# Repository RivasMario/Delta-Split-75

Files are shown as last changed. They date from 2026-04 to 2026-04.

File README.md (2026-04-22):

# Delta Split 75

Fork/mirror of the DeltaSplit75 V2 open-source keyboard: case DXF/DWG files, PCB gerbers, and 3D model. Reorganized for local iteration and fab prep.

## What this is

DeltaSplit 75 is a **dual-mode 75% keyboard**:

1. **One-piece mode** — left + right plates butt-join into a single unibody case; all keys present.
2. **Spread-split mode** — same PCB/plates but mounted in two separate shells with a physical gap between halves. At the seam there's a **detachable switch** that gets populated for one-piece mode and removed (or a blocker inserted) for spread mode.

The PCB is one ~322 × 120 mm board regardless of mode. Plates ship as **left + right DXFs** because the combined ~680 mm width exceeds most laser beds, and because the spread mode needs them as separate parts anyway.

## Layout

```
case/
  bezel/        top bezel — Standard / Winkeyless / blocked-corner
  left/
    plate/      MX, ALPS, ALPS+MX, MX Costars
    middle/     5× stacked in one DXF
    bottom/
  right/
    plate/      MX, ALPS, ALPS+MX   (no Costars variant)
    middle/
    bottom/
pcb/
  gerbers/      KiCad 4.0.6 output, 11 files (Cu/Mask/Paste/SilkS/Edge.Cuts/drills)
docs/
  DeltaSplit-Final.step    3D assembly
  deltasplit.pdf           original build doc
  PCB_Dimension.dwg
  ORIGINAL_README.md
archive/
  *.zip, *.bak             source archives, AutoCAD backups
```

## Stackup (top → bottom)

Designed for **3D printing** or acrylic stack. Total height ≈ **25.5 mm**.

| Qty | Component | Notes |
|----|---|---|
| 1  | Top Bezel | 3D print (one piece) |
| 2  | Switch Plates | Left + Right, 1.5mm Alu or 3D print |
| 2  | Mid Shells | Left + Right halves |
| 2  | Bottom Bases | Left + Right halves |

## Interconnect
*   **Original:** TRRS (unsafe hot-plugging).
*   **Modern (RP2040 Build):** USB-C to USB-C link.

## 3D print quantities (STLs in `output/3d/`)

Generated by `scripts/case_to_stl.py` — one STL per file, print the count listed.

| STL | Prints | Notes |
|-----|:---:|---|
| `bezel_standard.stl` / `bezel_winkeyless.stl` / `bezel_blocked.stl` | **1** | pick one variant |
| `plate_left_<variant>.stl` | **1** | pick one variant |
| `plate_right_<variant>.stl` | **1** | pick matching variant |
| `middle_left.stl` | **5** | STL contains one copy; source DXF had 5 stacked on sheet |
| `middle_right.stl` | **5** | same |
| `bottom_left.stl` | **1** |  |
| `bottom_right.stl` | **1** |  |

Total: 1 bezel + 2 plates + 10 middles + 2 bottoms = **15 parts** per keyboard.

## Next

See `PLATES.md` for plate variant matrix, `BUILD.md` for fab-order guide, `STATUS.md` for current issues / TODOs.

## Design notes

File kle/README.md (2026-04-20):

# KLE — DeltaSplit 75

`deltasplit75_raw.json` — user's on-record KLE for the DeltaSplit 75. Raw keyboard-layout-editor rows.

## Layout notes

- **Gap `{"x":2}`** in every row = the visual/physical split between LEFT and RIGHT halves.
- **Color coding:**
  - `#cccccc` — alphas
  - `#999999` — mods / function keys
  - `#6897ca` — arrow cluster
- **"Temp" keys** at end of rows 2–5 = placeholder labels on the right-hand column; rename when finalizing.
- **Row 6 (bottom)** has a 2u "Backspace" where a 2.75u Spacebar normally sits on the LEFT half — unusual. Check if this is the detachable seam switch or an intentional remap.
- **Seam switch / detachable key** — not yet identified in this KLE. If the spread-split variant omits a key, mark it with `{d:true}` (decal) or produce `deltasplit75_spread.json` variant.

## TODO

- [ ] Validate against PCB switch count (PCB `.kicad_pcb` TBD — currently only gerbers).
- [ ] Produce `deltasplit75_onepiece.json` and `deltasplit75_spread.json` variants.
- [ ] Wire into `KB_PLATE_VALIDATOR/scripts/build_plate.py --kle kle/deltasplit75_onepiece.json`.

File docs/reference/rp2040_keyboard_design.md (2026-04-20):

# RP2040 Keyboard PCB Design — Reference

Source: Gemini extraction of Noah Kiser's RP2040 hotswap keyboard build videos. Target KiCad ≥ 10.0.1 (2026-04-15). Use this as the schematic + layout scaffold for the DeltaSplit 75 v3 / RP2040 upgrade.

---

## 1. MCU — RP2040 power + peripheral baseline

### Power delivery

| Block | Part | Detail |
|---|---|---|
| USB-C receptacle | HRO TYPE-C-31-M-12 (or equiv) | CC1 + CC2 each pulled to GND via **5.1 kΩ 0402** (power negotiation) |
| ESD protection | SRV05-4 diode array | On D+/D−; routable footprint lets diff pair pass through IC center |
| Inrush protection | 500 mA PTC fuse | On VBUS before LDO |
| 3V3 LDO | XC6206 (or equiv) | VBUS → 3V3 |
| LDO decoupling | 1 µF in, 1 µF out | |
| RP2040 bulk | 10 µF | On 3V3 main input |
| RP2040 per-pin | 100 nF | Physically close to **every** 3V3 pin |
| Internal 1.1V reg | 1 µF | Dedicated |

### High-speed peripherals

| Block | Requirements |
|---|---|
| **QSPI flash** | W25Q128 (or equiv). 6 signals: CS, CLK, IO0–IO3. Direct pin-to-pin match to MCU. |
| **Oscillator** | 12 MHz SMD 3225 crystal → XIN/XOUT. **1 kΩ inline on XOUT**. 22 pF load caps on both lines, tied to GND plane. |
| **USB data** | **27 Ω series** on D+ and D−, placed immediately before MCU pins. |

---

## 2. Switch matrix footprint rules

- **Per-switch diode**: SOD-123 SMD, one per key, column → row direction (anti-ghost).
- **Diode placement**: bottom copper, physically between the large central mounting-pin hole and the two small switch contact holes. Saves space, enables cleaner trace routing.
- **CAD grid**: **0.79375 mm** (= 19.05 mm ÷ 24). This is the only grid on which 1U, 1.25U, 1.5U, 1.75U, 2.25U, 2.75U all land on exact fractions. Snap everything to it.

---

## 3. Multi-layout collision rules

Critical for DeltaSplit 75 since the KLE has a detachable seam switch and the plate variants support MX / ALPS / ALPS+MX / Costars.

### Soldered boards
- Multiple physical layouts can share one PCB with minimal issues — metal pins drop into shared holes.
- Minor pad vs stabilizer-screw conflict? **Rotate switch 180°** to resolve.

### Hotswap boards (DeltaSplit RP2040 target)
- Kailh hotswap sockets protrude horizontally off the back. Overlap with stab screw holes is common when supporting two layouts (e.g. ANSI Enter + ISO 1U).
- **90° rotation is forbidden.** MX stem cross is asymmetric (horizontal bar is thicker) — a 90°-rotated switch distorts keycaps.
- Resolution order:
  1. Drop screw-in stab support for the conflicting keys → force plate-mount stabs.
  2. If that's not enough, fork to separate Gerber sets per layout (e.g. ANSI-only vs ISO-only).

---

## 4. Trace routing hierarchy

Priority order for router / manual-routing:

1. **USB D+ / D−** — differential pair, side-by-side, **single layer, no vias**. Match length by routing.
2. **Crystal lines** — orient crystal at **45° to the MCU** so XIN/XOUT are inherently length-matched and short. Keep over a solid ground plane.
3. **Power (VBUS, 3V3)** — thick net class, ≥ **0.3 mm**. VBUS especially.
4. **Matrix grid**:
   - **Columns → top copper, vertical**
   - **Rows → bottom copper, horizontal**
   - No signal-blocking crossovers.
5. **GND** — never a trace. Fill all remaining space on both layers with **copper pour tied to GND**. Stitch front ↔ back with **aggressive via pattern** across the board.

---

## 5. Apply to DeltaSplit 75 rebuild

Matching this reference against the existing DeltaSplit 75 gerbers + KLE:

- **86 switches** (KLE count) → 86 diodes, 1 matrix, split into two blocks if the spread-split mode needs independent wiring. More likely: one matrix, ribbon/flex cable across the seam for the spread variant. Confirm from gerbers.
- **Edge.Cuts** is ~322 × 120 mm (single board, not split electrically) → matches "one PCB, two mounting modes" read.
- **Controller section** on DeltaSplit V2 gerbers sits in the LEFT-top region (see silkscreen "split left-F.SilkS.gto"). RP2040 + USB-C + QSPI + crystal + LDO all need to fit there. Measure available area before committing.
- **Grid**: redo all switch placements on 0.79375 mm grid when re-entering in KiCad.
- **Seam switch**: wire as normal matrix key, but call out in README that the key is physically optional depending on case mode.

---

## 6. Next actions

- [ ] Create `pcb/kicad/` with a fresh KiCad 10 project.
- [ ] Import gerbers as reference layer (KiCad: File → Import → Gerber).
- [ ] Build schematic from this scaffold: RP2040 + QSPI + USB-C + LDO + crystal + 86× switch/diode.
- [ ] Derive key-position table from KLE → CSV → switch footprint placements on the 0.79375 grid.
- [ ] Route per hierarchy §4.
- [ ] Cross-check board outline against `case/` plate DXFs — mounting holes must match.

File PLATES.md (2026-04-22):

# Plate Variants

All plate DXFs are **1.5 mm aluminium**, one per half. BBox from ezdxf parse.

| Variant | Left (W×H mm) | Right (W×H mm)  | Notes |
|---|---|---|---|
| MX | 340.2 × 129.3 | 351.9 × 129.3 | standard MX switch cutouts |
| ALPS | present | present | |
| ALPS+MX | present | present | hybrid — both footprints |
| MX Costars | 340.2 × 129.3 | present | Costar stabilizer cutouts |

## Middle layers

Single DXF per side contains 5 vertically stacked layers (~142 mm each × 5 = 710 mm tall). Split before ordering if fab bed < 750 mm.

| Side  | W × H mm |
|---|---|
| Left  | 340.2 × 710.5  |
| Right | 351.9 × 731.2  |

## Bottom layer

| Side  | W × H mm |
|---|---|
| Left  | 340.2 × 129.3  |
| Right | 351.9 × 129.3  |

## Bezel (single DXF, one piece)

Bezel variants are full-width single pieces, not split:

| Variant | Size (W×H mm)  |
|---|---|
| Standard | 345.1 × 129.3  |
| Winkeyless | 372.1 × 129.3  |
| Blocked corner | 345.1 × 129.3  |

## Stitch seam

Left and bottom layers butt-join in world coords at x ≈ 320–372 mm. When fabbed, halves align by shared mounting-hole positions — no keying feature in DXF.

## Why left/right plate variants differ

Cutout counts between matching left/right variants aren't always symmetric (e.g. MX+ALPS left ≠ right by one cutout). This tracks the PCB: at the stitch seam there are **two snap-off switch positions labeled `B1` and `B2`** on the motherboard. Populated for one-piece mode, snapped off (or left unpopulated) for spread-split mode. Plate cutouts for `B1`/`B2` only exist on the half(s) hosting those positions, so per-variant the side with the extra switch has one more plate cutout than its mirror.

## Known gaps

- **Bezel DXFs measured** for Winkeyless / blocked-corner.
- **RIGHT Costars plate created** by mirroring/translating stabilized geometry.

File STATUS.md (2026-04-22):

# Status / TODO

## Done

- [x] Inventoried source zip contents (case + gerbers).
- [x] Reorganized into `case/`, `pcb/`, `docs/`, `archive/`.
- [x] Git repo initialized.
- [x] README + PLATES + BUILD markdowns written.

## Lint results (2026-04-20)

`scripts/lint_dxf.py` — SCS-style pre-flight.

| DXF | Dangling endpoints | Verdict |
|---|---|---|
| ALPS LEFT B | 0 | clean |
| ALPS+MX LEFT B | 6 | 2× broken rects near (221.9,144.6) and (265.7,165.1) |
| MX LEFT B COSTARS | 0 | clean |
| MX LEFT B | 1 | orphan line at (257.3,380.9) — missing 3 sides of a switch cutout |
| ALPS RIGHT B | 1 | 1× orphan line |
| ALPS+MX RIGHT B | 0 | clean |
| MX RIGHT B | 1 | orphan line at (269.0,245.5) — missing 3 sides of a switch cutout |

No zero-length segs, dup vertices, unclosed polylines, or bbox overlaps. Orphan lines are ≥14 mm — SCS won't auto-repair; fab will either reject or laser-cut them as open scores.

## Open

- [x] Generate **two KLE JSONs** for `KB_PLATE_VALIDATOR/scripts/build_plate.py`:
  - `kle/deltasplit75_onepiece.json` — full layout incl. seam switch.
  - `kle/deltasplit75_spread.json` — seam switch omitted.
- [x] Measure Winkeyless + blocked-corner bezel DXFs, populate `PLATES.md` bezel table.
- [x] Generate/extract KLE JSON for the DeltaSplit layout so `KB_PLATE_VALIDATOR/scripts/build_plate.py` can consume it.
- [x] Mirror LEFT Costars geometry → create RIGHT Costars plate DXF.
- [ ] Count + locate mounting holes per layer; decide screw size for `BUILD.md`.
- [ ] Verify gerber file extensions against target fab (`gm1` → `gml`?).
- [ ] Render case/plate preview PNGs into `docs/` for README.

## PCB reverse-engineering findings (2026-04-21)

Gerber silkscreen (`output/pcb_preview/F.SilkS.png`) + drill analysis (`pcb/gerbers/split left*.drl`):

- **Designer/year**: `DeltaSplit75 R2 xyxjj 2017`.
- **MCU**: socketed **ProMicro** daughterboard (2× 12-pin headers per half, 48× Ø1.016mm PTH), not SMT ATmega32u4.
- **Inter-half link**: TRRS 4-pin jack (marked `4PIN` on silk; 9× Ø0.991mm PTH matches 2× 4-pin jacks + mounting).
- **Per-key (86 switches)**: 5-pin MX footprint — 2× Ø1.499mm PTH signal, 2× Ø1.702mm NPTH plastic posts, 1× Ø3.988mm NPTH center post. Plus 1N4148 diode per key.
- **Mounting**: 12× Ø3.048mm NPTH = M3 case screws.
- **Stabilizers**: PCB-mount (additional Ø1.702/Ø3.988 NPTH beyond 86-switch count).
- **On-silk assembly order**: "1. Diodes → 2. ProMicro headers → 4. TRRS jacks → 5. Switches → 6. ProMicro. **INSTALL PRO MICRO LAST**."
- **B1/B2 switches**: dual-switch position in bottom row (confirms snap-off position note in `PLATES.md`).

Implication: **no MCU/crystal/USB on the board** — all on ProMicro module. Schematic reduces to matrix + 2× ProMicro headers + 2× TRRS. Trivial compared to a full ATmega32u4 build.

## Phase A — recreate original PCB in KiCad

Target project: `pcb/DeltaSplit_ProMicro.{kicad_pro,kicad_pcb}` (bootstrapped via `GerbView → File → Export → Export to Pcbnew`).

- [x] Export gerbers to `.kicad_pcb` via GerbView (graphics-only, no nets).
- [ ] Build schematic `pcb/DeltaSplit_ProMicro.kicad_sch`:
  - 86× `SW?` (marbastlib MX hotswap or solder footprint) + 86× `D?` (1N4148, THT DO-35 or SOD-123).
  - 2× ProMicro 12-pin header pair (Keebio-Parts `ProMicro.kicad_mod`).
  - 2× TRRS 4-pin jack (`PJ-320A` — check marbastlib-various or Keebio-Parts).
  - PCB-mount stabilizers for space/shift/backspace/enter (marbastlib `Stabilizer_Cherry_MX`).
  - Matrix wiring: rows × cols per ProMicro GPIO.
- [ ] Import netlist to existing `.kicad_pcb`.
- [ ] Place footprints over gerber-graphics by matching pad centers; KLE Placer for switch grid after anchor switch placed.
- [ ] Route to match visible copper — or use schematic-driven clean routing; rip graphics once done.
- [ ] ERC + DRC clean.

## Phase B — RP2040 drop-in (revised)

Easiest: **ProMicro RP2040 module** (Elite-Pi / 0xCB Helios / SparkFun). Pin-compatible with existing ProMicro headers → **zero PCB/schematic changes**. Just flash QMK/KMK with RP2040 matrix config.

Harder direct-SMT RP2040 path (calliah333 schematic) only if dropping daughterboard for cost/slim-profile reasons.

## RP2040 rebuild track

References:
- `docs/reference/rp2040_keyboard_design.md` — Noah-Kiser-derived BOM + routing constants.
- `docs/reference/rp2040_designguide_schematic.md` — calliah333 canonical RP2040 reference schematic (ref-designator breakdown).
- `docs/reference/nckiser_repos.md` — Noah's GitHub repos cloned to `../../NCKiser_refs/`.
- `docs/reference/kicad_toolchain.md` — install order for KiCad 10 + marbastlib + KLE placer + Keebio-Parts.

**RP2040 port strategy** (revised given ProMicro-based original):
Easiest path = **drop-in ProMicro-RP2040 daughterboard**: Elite-Pi, 0xCB Helios, or SparkFun ProMicro RP2040. Pin-compatible with original ProMicro headers → zero PCB changes needed for RP2040. The calliah333 full-SMT RP2040 schematic is only relevant if going direct-SMT MCU (harder rebuild, more components).

### Phase 0 — install toolchain (one-time)

- [ ] Install KiCad 10.0.1.
- [ ] PCM: install **ebastler/marbastlib** (upstream, not NCKiser fork).
- [ ] PCM: install **zykrah/kicad-kle-placer** via `https://raw.githubusercontent.com/zykrah/zykrah-kicad-repository/main/repository.json`.
- [ ] Link `Keebio-Parts.pretty` (from `../../NCKiser_refs/`) in `fp-lib-table`.

### Phase 1 — project scaffold

- [ ] Copy `le_chiffre_keyboard_stm32/kicad/pcb/` layout skeleton to `pcb/kicad/`.
- [ ] Add KiCad project: `pcb/kicad/deltasplit75_rp2040.kicad_pro`.
- [ ] Copy `kibot.yml` → `.github/workflows/` once the KiCad project builds.

### Phase 2 — schematic (reference: `docs/reference/rp2040_designguide_schematic.md`)

- [ ] Open RP2040-Guide.pdf side-by-side with KiCad; replicate MCU block 1:1 (U3 RP2040, U1 W25Q128, U2 USBLC6 ESD, U4 XC6206 LDO, Y1 12MHz + 22pF + 1kΩ, F1 500mA PTC, SW1 boot button, J2 SWD).
- [ ] Set exact passive values per the PDF table: 5.1kΩ CC pulldowns, 27Ω USB series, 10µF bulk, 100nF per 3V3 pin, 1µF on 1V1/LDO in/out.
- [ ] Create hierarchical `key_matrix.kicad_sch` with 86× SW + 86× D + stabilizers. Name SW1…SW86 so KLE-placer can match.

### Phase 3 — PCB layout

- [ ] Import existing DeltaSplit gerbers as reference layer (File → Import → Gerber).
- [ ] Place ONE switch + its diode manually at the desired relative offset.
- [ ] Run **KLE Placer** plugin with `kle/deltasplit75_raw.json` → auto-places remaining 85 switches + diodes on the 0.79375 mm grid.
- [ ] Route per §4 hierarchy (USB diff → crystal → power → matrix → GND pour + stitching).
- [ ] Cross-check board outline vs `case/` plate DXFs — mounting holes align.
- [ ] Decide hotswap-vs-solder; if hotswap, apply §3 collision rules for the detachable seam switch.

### Phase 4 — KLE enrichment for placer

- [ ] Add label-position-4 reference numbers (`1`…`86`) to every key in `kle/deltasplit75_raw.json` — required for **Specific Reference Mode** (needed once any rotated key is introduced).
- [ ] Add multilayout labels (position 3) if supporting ANSI/ISO/Costar variants on one PCB.

## Nice-to-have

- [ ] Source a 3D-printable version of bezel (instead of laser-cut acrylic).

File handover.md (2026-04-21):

# Handover Information
Repository Name: My Repository
Date: $(date)
## Contributions
Author: RivasMario
## Handover\n\n- **Author:** RivasMario\n- **Project Description:** This repository contains files for a dual-mode 75% keyboard, including case DXF/DWG files, PCB gerbers, and 3D models. The README provides detailed information on the project structure, layout, stackup, and build process.
## Handover\n\n- **Author:** RivasMario\n- **Project Description:** This repository contains files for a dual-mode 75% keyboard, including case DXF/DWG files, PCB gerbers, and 3D models. The README provides detailed information on the project structure, layout, stackup, and build process.

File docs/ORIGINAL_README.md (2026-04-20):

# DeltaSplit75-Case-files

Files available in dxf and dwg, dimensions in mm

Known Working configuration
2x3mm acryic top bezel
1x1.5mm aluminium plate
5x3mm acrylic middle layers
1x3mm acrylic bottom layer

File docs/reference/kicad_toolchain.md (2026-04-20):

# KiCad toolchain for DeltaSplit 75 rebuild

Install once; reuse for every future keyboard project.

## 1. KiCad 10.0.1 (released 2026-04-15)

Stable. All reference schematics here are KiCad 6/7 — KiCad 10 auto-upgrades on open.

## 2. Libraries — install via PCM (Plugin & Content Manager)

### marbastlib (upstream, **not** the NCKiser fork)

- URL: [github.com/ebastler/marbastlib](https://github.com/ebastler/marbastlib)
- Install: PCM → add repository OR manually symlink `ebastler_marbastlib/footprints/*.pretty` + `symbols/*.kicad_sym` into project `fp-lib-table` / `sym-lib-table`.
- Contents (upstream is richer than the NCKiser fork):
  - `marbastlib-mx.pretty` — MX + hotswap
  - `marbastlib-choc.pretty` — Kailh Choc low-profile
  - `marbastlib-he.pretty` — Hall Effect
  - `marbastlib-hitek.pretty` — Hi-Tek
  - `marbastlib-various.pretty` — USB-C (HRO M-14), ProMicro, encoders, nRF52840, mousebites
  - Matching `.kicad_sym` for each

### Keebio-Parts.pretty (from NCKiser fork)

- Local: `../../NCKiser_refs/Keebio-Parts.pretty/`
- Contents: ATMEGA32U4, ProMicro variants, **Crystal_SMD_3225-4pin** (exact crystal package our reference specifies), 0402/0603/0805 passives, audio jack, RJ-45.
- Add to `fp-lib-table`.

### KiCad 10 built-ins (for RP2040 specifically)

- Symbol: `MCU_RaspberryPi:RP2040`
- Footprint: `Package_DFN_QFN:QFN-56-1EP_7x7mm_P0.4mm_EP3.2x3.2mm`
- Crystal footprint: use Keebio-Parts `Crystal_SMD_3225-4pin_3.2x2.5mm.kicad_mod`
- USB-C: use `marbastlib-various/USB_C_Receptacle_HRO_TYPE-C-31-M-14.kicad_mod`
- ESD: `Package_TO_SOT_SMD:SOT-23-6`

## 3. KLE auto-placer — zykrah/kicad-kle-placer

- Source: [github.com/zykrah/kicad-kle-placer](https://github.com/zykrah/kicad-kle-placer)
- Local: `../../NCKiser_refs/kicad-kle-placer/`
- **Install via PCM**: Repository manager → paste `https://raw.githubusercontent.com/zykrah/zykrah-kicad-repository/main/repository.json` → install "KLE Placer" → Apply.
- What it does: reads a KLE JSON, auto-places matching switch/stab/diode footprints onto the PCB based on schematic reference order (SW1, SW2, ...).
- Also places diodes: check `Move Diodes` + `Move diodes based on first switch and diode`; place the first switch+diode pair manually, plugin replicates the offset to all others.

### Workflow for DeltaSplit 75

1. Finalize the schematic (86 switches named SW1–SW86 + matching D1–D86 diodes + stabilizers S7/S10/S25/…).
2. Open PCB editor; import netlist.
3. Place first switch + its diode exactly where you want them relative to each other.
4. Tools → External Plugins → KLE Placer.
5. Select `kle/deltasplit75_raw.json`.
6. Enable **Specific Reference Mode** if rotated keys are added (required for any non-zero rotation).
7. Run → all 86 switches + diodes + stabs snap into place on the 0.79375 mm grid.

### KLE label guidelines (for the placer)

- Label position **3** — multilayout index (for ANSI/ISO variants).
- Label position **4** — reference number (e.g. `1` means `SW1`). **Required** for Specific Reference Mode + rotated keys.
- Label position **5** — multilayout value.
- Label position **9** — `F` to flip stabilizer.
- Label position **10** — extra rotation in degrees (for north-facing keys etc.).

The current `kle/deltasplit75_raw.json` has none of these — add them before running the placer.

## 4. Reference schematic — calliah333 RP2040-Guide.pdf

- Source: [github.com/calliah333/RP2040-designguide](https://github.com/calliah333/RP2040-designguide)
- Local: `../../NCKiser_refs/rp2040_designguide/RP2040-Guide.pdf`
- See `rp2040_designguide_schematic.md` for a ref-designator breakdown of every component on the schematic.

## Install order (one-time)

1. Install KiCad 10.0.1.
2. Open PCM → add marbastlib repository, install.
3. PCM → add zykrah's repository (URL above), install KLE Placer.
4. Clone ebastler/marbastlib (done) and sym/fp-link it into our project.
5. Clone Keebio-Parts.pretty (done via NCKiser fork) and link.

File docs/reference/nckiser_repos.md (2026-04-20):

# Noah Kiser reference repos

Cloned to sibling dir: `../../NCKiser_refs/` (not tracked in this repo — shared reference for all future keyboard builds).

Source: [github.com/NCKiser](https://github.com/NCKiser) (50 public repos as of 2026-04-20).

## What's here and why it matters

### Gold-standard template — `le_chiffre_keyboard_stm32`

Complete, modern keyboard project with the layout structure DeltaSplit 75 should mirror:

```
le_chiffre_keyboard_stm32/
├── kicad/pcb/
│   ├── key_matrix.kicad_sch          ← hierarchical schematic pattern
│   ├── library/
│   │   ├── MX_Alps_Hybrid.pretty/    ← 1U, 1.25U, 1.5U, 1.75U, 2U, 2.25U, 2.75U, 3U, 10U + vertical/reversed-stab variants
│   │   ├── modified_footprints.pretty/   (custom SK6812, rotary encoder, SPST)
│   │   └── 3d_models/                ← HRO TYPE-C-31-M-12.step, Kailh Hotswap.step, CherryMX.step, keycap .steps
│   └── config.kibot.yaml             ← CI config for auto-gerbers
├── case/                             ← STL for 3D print
├── documentation/                    ← auto-generated schematic PDF, Edge_Cuts.dxf, ibom.html, 3D step
├── firmware/                         ← prebuilt vial .bin
└── .github/workflows/kibot.yml       ← CI that rebuilds docs on push
```

**Action:** copy this directory skeleton when we start `pcb/kicad/` in Delta-Split-75.

### Raw tutorial artifact — `TKL_VIDEO`

Actual KiCad 7 project built live in Noah's TKL tutorial. Files: `TKL_Video.kicad_pcb`, `TKL_Video.kicad_sch`, `TKL_Video.kicad_pro`. Plus `TKL_Video-backups/` — 15+ incremental snapshots from 2023-05-23 → 2023-05-31 showing the exact sequence of design steps. **Open in KiCad and step through the backups in order to trace his workflow.**

### Footprint libraries

| Lib | Count | What |
|---|---|---|
| `marbastlib/marbastlib-mx.pretty` | 36 | MX switch + hotswap variants, all U widths |
| `marbastlib/marbastlib-choc.pretty` | 10 | Kailh Choc low-profile |
| `marbastlib/marbastlib-various.pretty` | 27 | USB-C (HRO TYPE-C-31-M-14), ProMicro, rotary encoders, nRF52840 modules, mousebites |
| `Keebio-Parts.pretty` | 20+ | ATMEGA32U4, ProMicro variants, crystals (3225 pkg — **exactly the 12MHz pkg our reference calls for**), 0402/0603/0805 passives |

**Action:** add these as KiCad project libraries. Neither has a direct **RP2040 QFN-56** footprint — use KiCad 10's built-in `MCU_RaspberryPi:RP2040` + `Package_DFN_QFN:QFN-56-1EP_7x7mm_P0.4mm_EP3.2x3.2mm`.

### Closest sibling board — `kiao`

STM32F072 in a Seeedstudio XIAO form factor. Relevant because it's a complete, compact MCU carrier with USB-C + decoupling + crystal — same class of design as an RP2040 carrier. Full KiCad project + production files (BOM, placement CSV, gerbers zip).

**Note:** NOT RP2040. Noah doesn't have a published RP2040 repo in the list. For the RP2040 reference design, fall back to the official Raspberry Pi RP2040 Minimal Design or the Pico schematic (both public) — then apply our `rp2040_keyboard_design.md` constants on top.

### Useful secondaries

- **`Monorail-Memoria`** — hotswap drop-in PCB with `rev 1.1/` and `rev 2.0/` side by side. Study the diff to learn what Noah changed in revision.
- **`Piggyback`** — 32u4 carrier that sits between switches. Same mechanical constraint DeltaSplit's seam switch imposes — study the board-outline + clearance tricks.
- **`le_chiffre_keyboard_stm32`** also has the cleanest `kibot.yml` — copy for CI.

## Reuse plan for DeltaSplit 75 RP2040 rebuild

1. **Structure**: clone `le_chiffre_keyboard_stm32`'s directory tree under our `pcb/kicad/`.
2. **Libraries**: symlink or vendor `marbastlib-mx.pretty` + `Keebio-Parts.pretty` + `le_chiffre .../MX_Alps_Hybrid.pretty` into `pcb/kicad/library/`.
3. **Schematic scaffold**: start from `TKL_Video.kicad_sch` (open in KiCad 10 — it'll auto-upgrade from 7). Strip the TKL-specific 87 switches, replace matrix block with the DeltaSplit 86-key grid.
4. **RP2040 block**: use KiCad 10 built-in symbols + `docs/reference/rp2040_keyboard_design.md` constants for passive values.
5. **CI**: copy `le_chiffre .../kibot.yml` to `.github/workflows/` once the KiCad project compiles.

## License note

All NCKiser repos are permissively licensed (check individual LICENSE files — `le_chiffre` is GPL v2, `marbastlib` has its own terms). Any vendored footprints must preserve their license headers.

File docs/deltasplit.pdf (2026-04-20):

# Warning: I’m terrible at documentation, so if any section is unclear

please do not hesitate to contact me either via email, reddit or discord, where I can better help you with your problem.

# Follow instructions to see the order of assembly

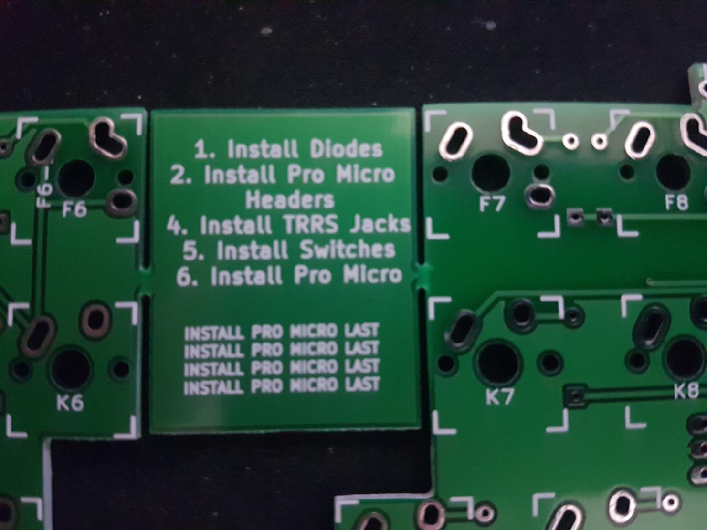
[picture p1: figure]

# Solder the diodes, black line pointing towards the square pad

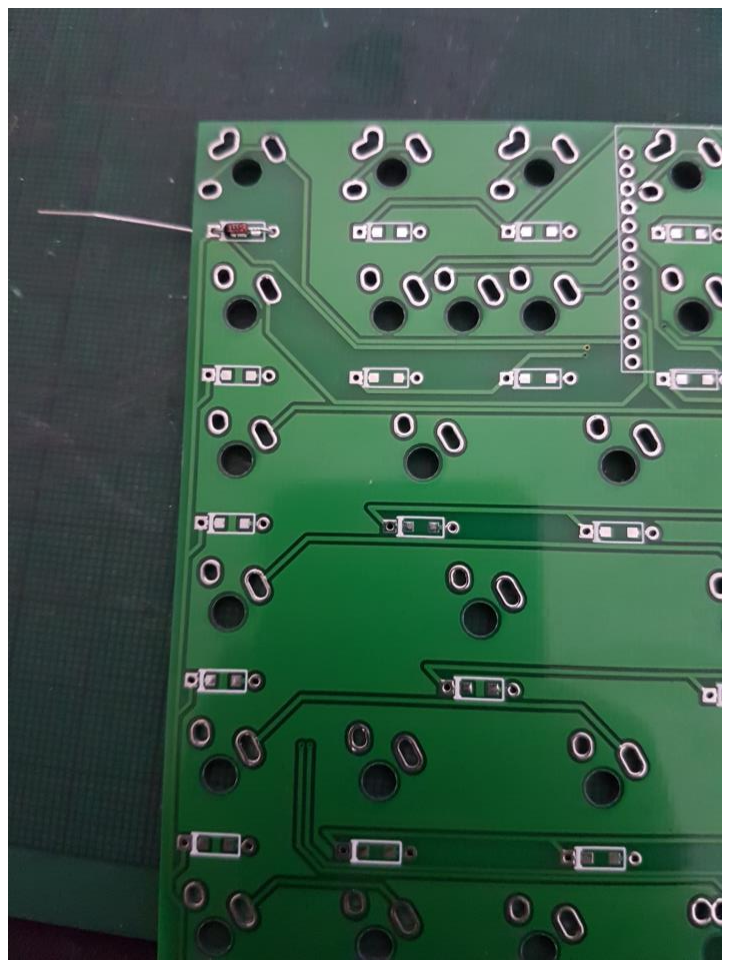
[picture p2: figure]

# Solder Pro Micro headers/trrs jacks

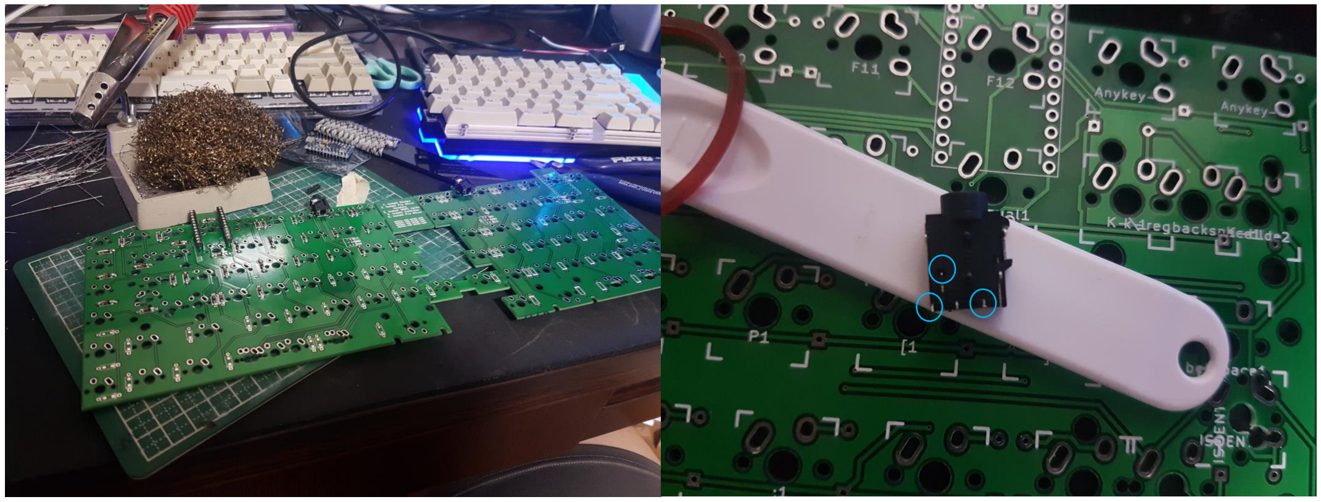
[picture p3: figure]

## You can opt to use IC sockets as well for the pro micro to enable easy swapping of the pro micro

## Trim the 7-pin TRRS jacks accordingly before soldering

# Solder switches

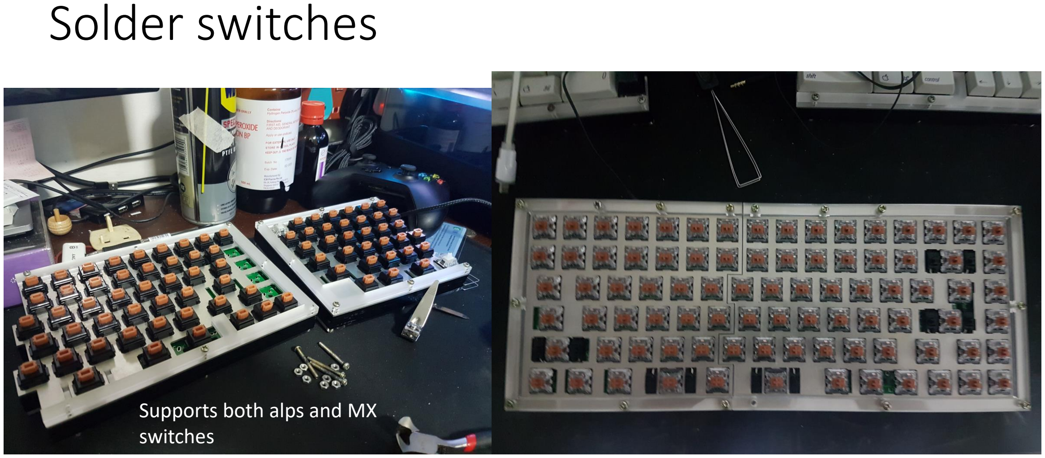
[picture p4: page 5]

## Supports both alps and MX switches

# Solder pro micro in these positions

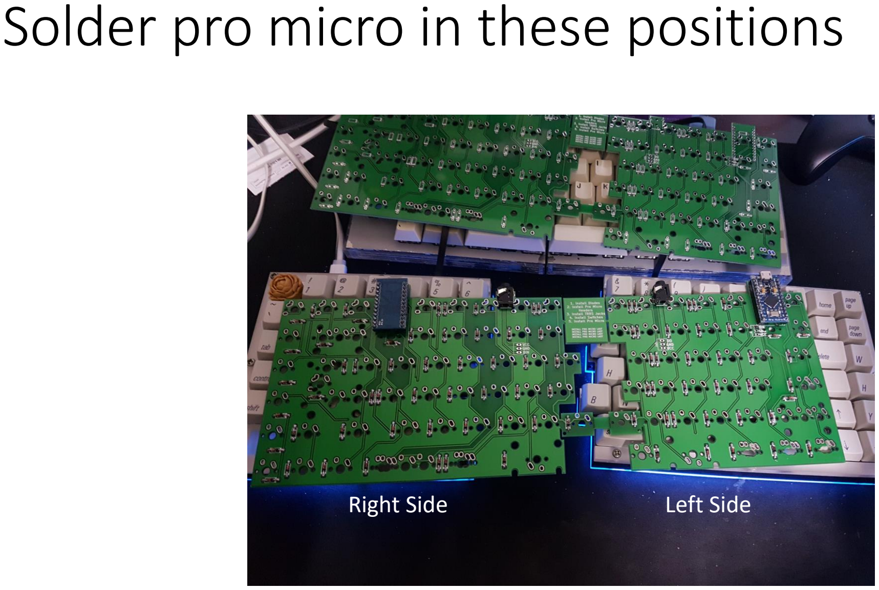
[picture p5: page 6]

Right Side | Left Side

# Flashing Guide

1) Set up a build environment for making and compiling the firmware
- Guide for this can be found here: https://docs.qmk.fm/build_environment_setup.html
- Notepad++ is nice to have if you need a good text editor
2) Download the DeltaSplit75 Firmware here: https://github.com/xyxjj/qmk_firmware/tree/master/keyboards/DeltaSplit75
- If you already have the qmk firmware you can just add the deltasplit75 folder to your existing firmware folder
3) Edit your keymap in DeltaSplit75/keymaps/Default
- If you have one of my prototype PCBs with a mislabeled silkscreen, edit it in ProtoSplit instead (see keymap editing for a guide to which keycode to edit)
4) Run the following commands depending on which PCB you have. The built hex files can be found in a .build folder in the main directory

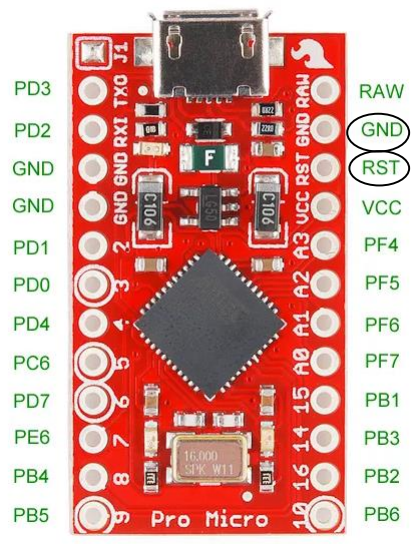
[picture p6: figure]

5) Upload firmware using an uploader of your choice
- personally I use xloader, you can get it here: https://www.lewys.eu/dev/XLoader.zip
- Select the built hex file in xloader
- Put the pro micro in to the bootloader mode by bridging RST and GND twice
- adjust the COM port in xloader to the appropriate one (there should be a new COM port that shows up) and hit upload
- do the same step for both sides
- if everything is done right the keyboard should work
- ensure both halves are connected with a TRRS cable with 3 rings on the tip, other wise it will not work

## Edit this for

# Keymap editing (for Default Keymap)

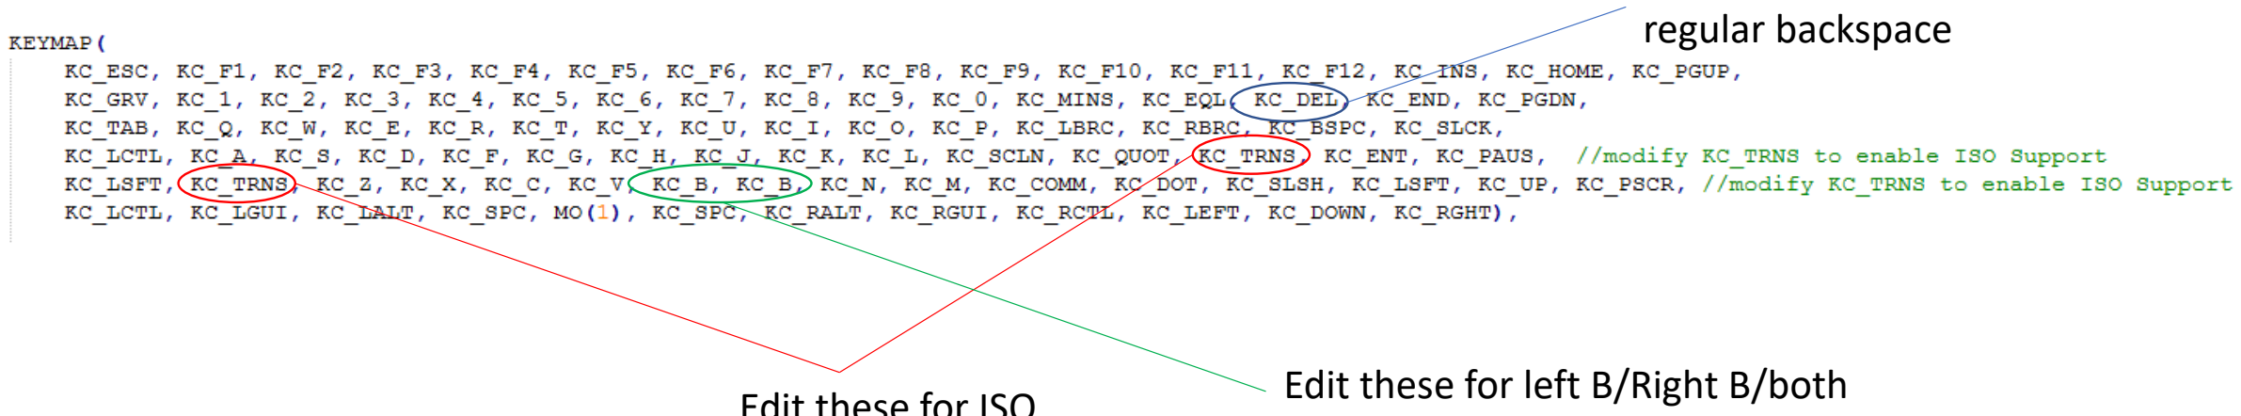
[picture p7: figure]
regular backspace; Edit these for left B/Right B/both

## Edit these for ISO layout

## Edit this for regular backspace

# Keymap editing (for ProtoSplit Keymap)

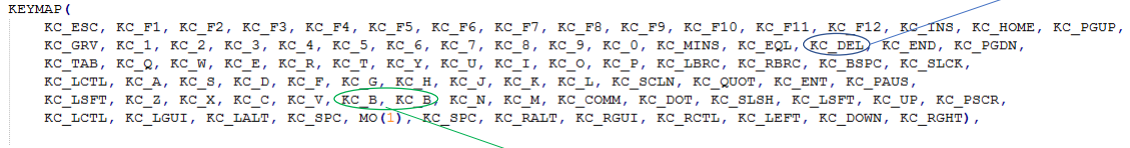
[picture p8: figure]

## Edit these for left B/Right B/both

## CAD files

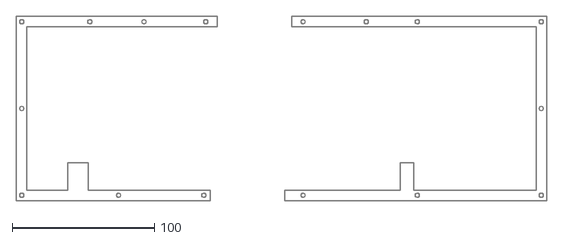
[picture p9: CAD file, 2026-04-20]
case/bezel/top bezel - Winkeyless.dxf
372.1 x 129.3

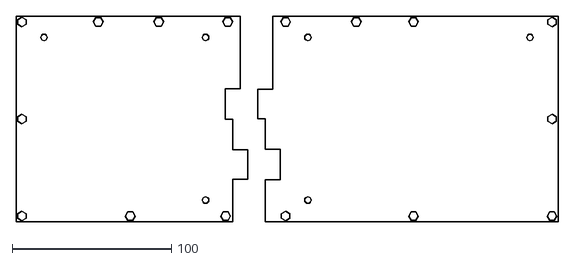
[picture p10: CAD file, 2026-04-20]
case/left/bottom/Bottom Layer - LEFT B.dxf
340.2 x 129.3

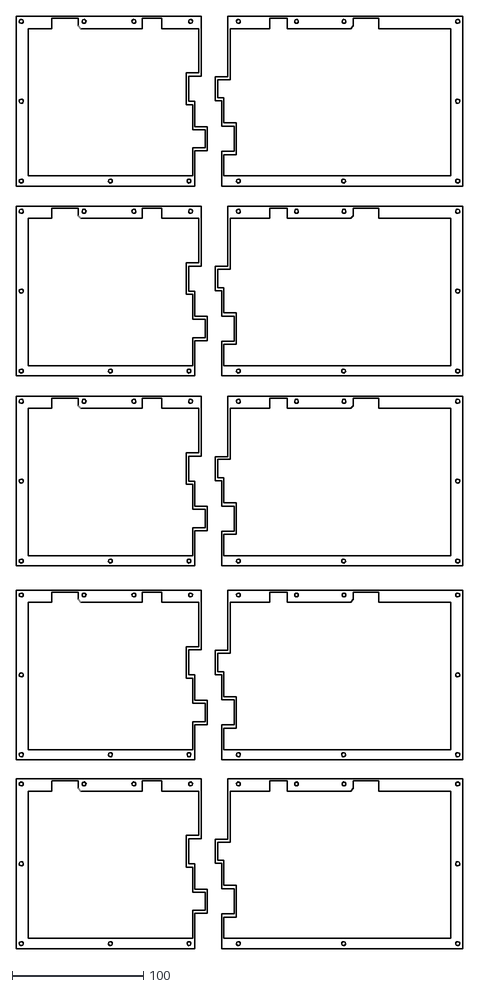
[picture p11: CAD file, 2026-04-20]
case/left/middle/Middle layers - LEFT B.dxf
340.2 x 710.5

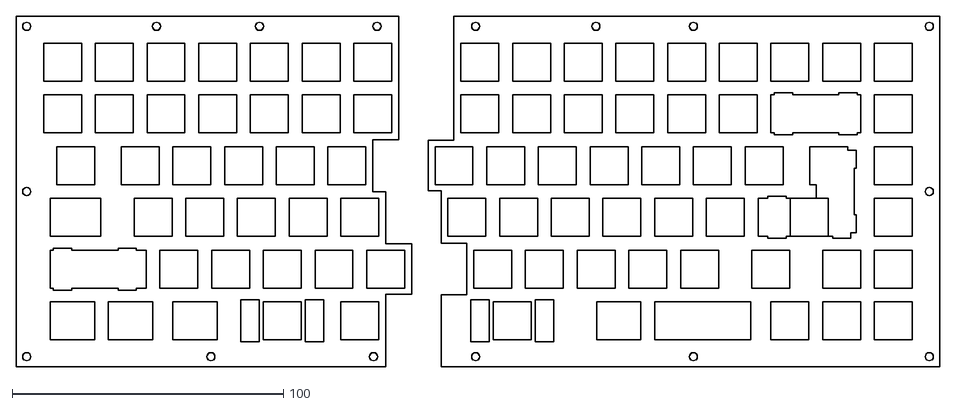
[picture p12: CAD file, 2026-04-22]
case/left/plate/MX LEFT B.dxf
340.2 x 129.3

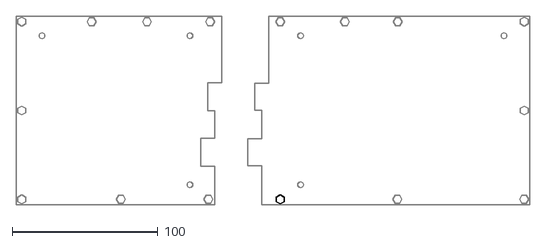
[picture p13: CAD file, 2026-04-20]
case/right/bottom/bottom layers - RIGHT B.dxf
351.9 x 129.3

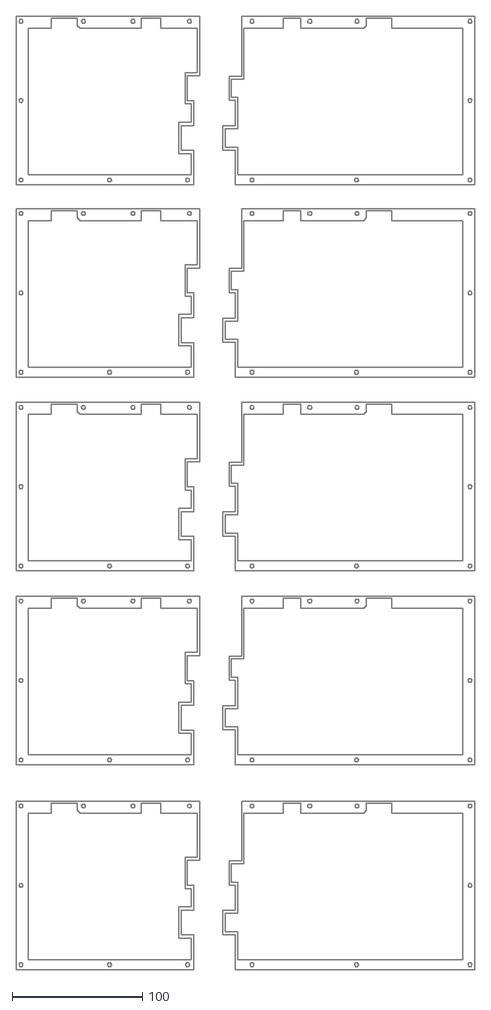
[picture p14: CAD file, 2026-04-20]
case/right/middle/middle layers - RIGHT B.dxf
351.9 x 731.2

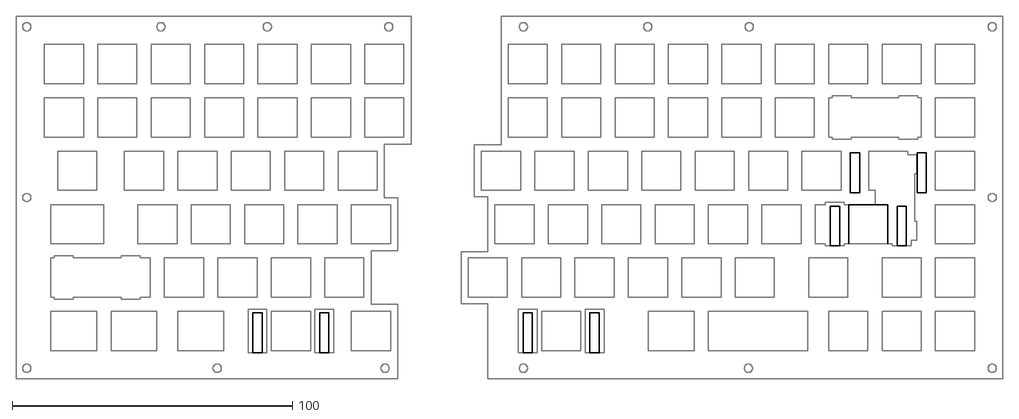
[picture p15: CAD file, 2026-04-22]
case/right/plate/MX RIGHT B COSTARS.dxf
351.9 x 129.3

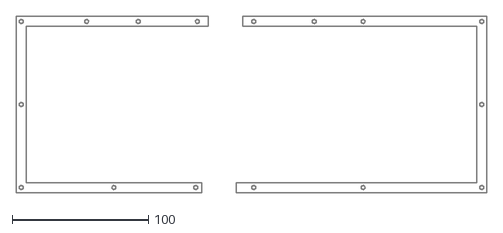
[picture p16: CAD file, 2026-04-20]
case/bezel/top bezel - Standard.dxf
345.1 x 129.3

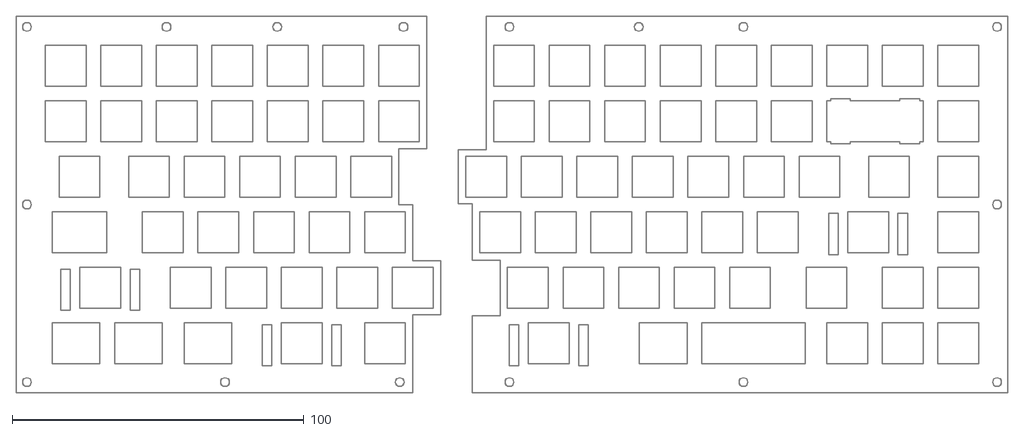
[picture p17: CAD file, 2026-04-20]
case/left/plate/MX LEFT B COSTARS.dxf
340.2 x 129.3

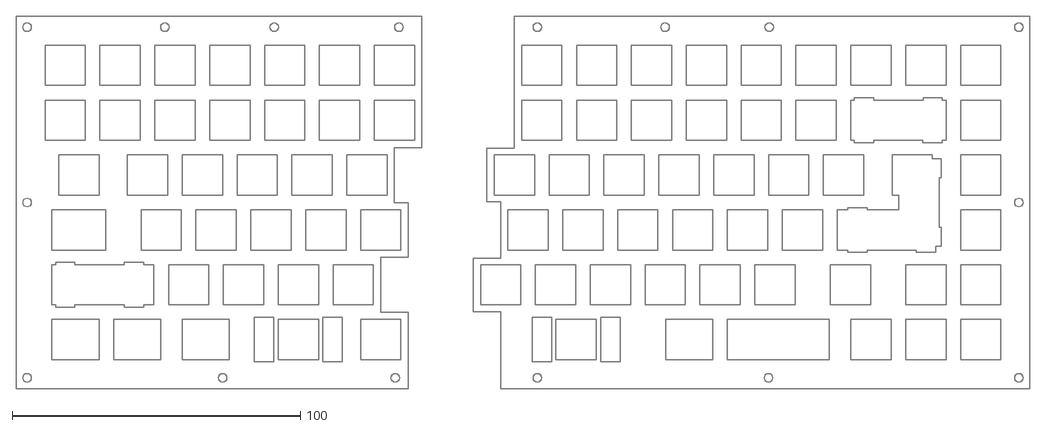
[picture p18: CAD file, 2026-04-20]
case/right/plate/MX RIGHT B.dxf
351.9 x 129.3

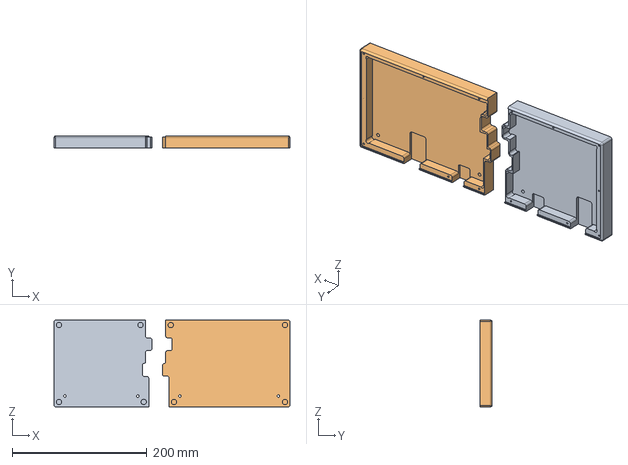
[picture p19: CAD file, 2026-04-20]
docs/DeltaSplit-Final.step
350.8 x 18.0 x 129.3 mm
Left
Right

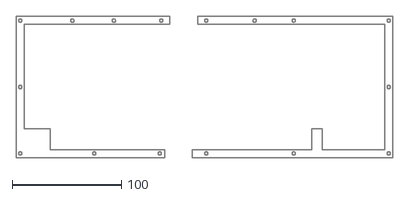
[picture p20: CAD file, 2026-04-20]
case/bezel/top bezel - blocked corner.dxf
345.1 x 129.3

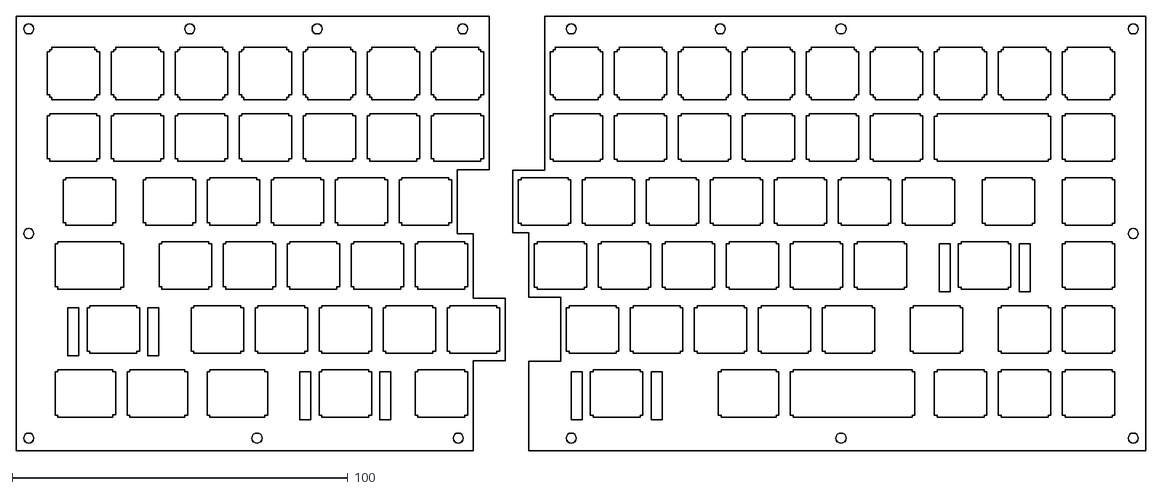
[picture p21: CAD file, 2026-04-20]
case/left/plate/ALPS+MX LEFT B.dxf
336.2 x 129.3

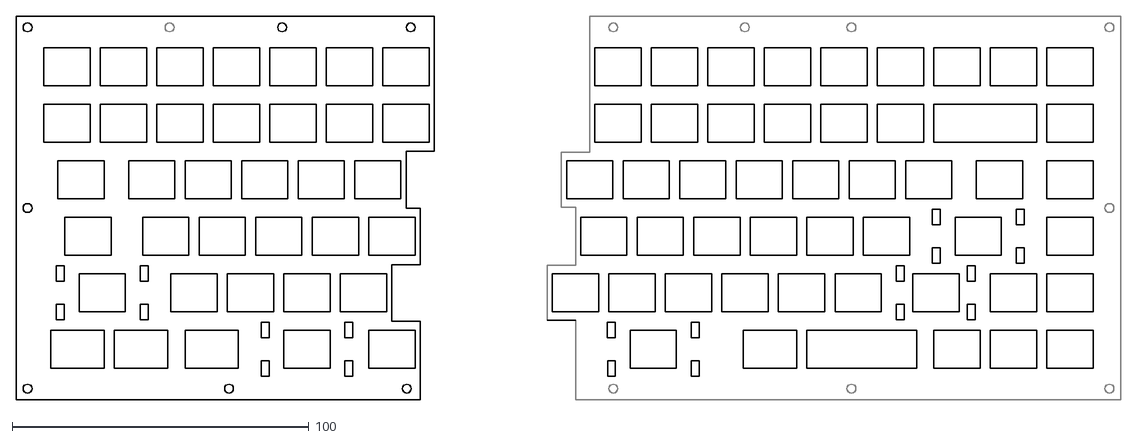
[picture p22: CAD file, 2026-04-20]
case/right/plate/ALPS RIGHT B.dxf
372.1 x 129.3

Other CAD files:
docs/PCB_Dimension.dwg
case/left/plate/ALPS LEFT B.dxf
case/right/plate/ALPS+MX RIGHT B.dxf
case/bezel/top bezel - Standard.dwg
case/bezel/top bezel - Winkeyless.dwg
case/bezel/top bezel - blocked corner.dwg
case/left/bottom/Bottom Layer - LEFT B.dwg
case/left/middle/Middle layers - LEFT B.dwg
case/left/plate/ALPS LEFT B.dwg
case/left/plate/ALPS+MX LEFT B.dwg
case/left/plate/MX LEFT B COSTARS.dwg
case/left/plate/MX LEFT B.dwg
case/right/bottom/bottom layers - RIGHT B.dwg
case/right/middle/middle layers - RIGHT B.dwg
case/right/plate/ALPS RIGHT B.dwg
case/right/plate/ALPS+MX RIGHT B.dwg
case/right/plate/MX RIGHT B.dwg

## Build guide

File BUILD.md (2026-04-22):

# Build / Fab Order Guide

## PCB (RP2040 SMD Version)

- Single board designed to be snapped into two halves.
- MCU: RP2040 (direct SMT).
- Link: **USB-C to USB-C cable**. 
- *Caution:* Use a standard USB-C cable. The link uses the CC lines/Differential pairs for serial communication.

## Case (3D Printed)

1. Use STLs in `output/3d/`.
2. Recommended Material: PETG or PLA+.
3. Infill: 20-30% Grid for weight and sound dampening.
4. Hardware: M3 × 30mm screws + M3 nuts.

## Assembly Order

1. Print Left/Right halves.
2. Snap PCB halves apart.
3. Install USB-C mid-link jacks.
4. Bolt through: Bezel → Plate → Shell → Bottom.

## Open questions

- Screw spec: original docs don't list diameter/length. Check `docs/deltasplit.pdf`.
- Standoff height: derive from total stack 22.5 mm minus hardware.

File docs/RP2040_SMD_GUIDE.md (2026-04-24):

# RP2040 SMD Implementation Guide (Lessons from SKYWAY-96)

This guide provides the verified hardware and firmware stack used in the successful SKYWAY-96 project, optimized for JLCPCB SMT assembly.

## 1. Verified BOM (LCSC Parts)

| Component | Description | Part Number (LCSC) | Notes |
|---|---|---|---|
| **MCU** | Raspberry Pi RP2040 | C2040 | QFN-56 |
| **Flash** | W25Q128JVS | C82431 | 128Mb (16MB) SOIC-8 |
| **LDO** | AMS1117-3.3 | C6186 | 5V to 3.3V Regulator |
| **ESD** | PRTR5V0U2X | C16223 | USB Data Protection |
| **Crystal** | 12MHz SMD | C115962 | 3.2x2.5mm |
| **USB-C** | HRO Type-C-31-M-12 | C165948 | 16-pin SMT |

## 2. Firmware Configuration (QMK keyboard.json)

The RP2040 build for QMK is significantly cleaner using the data-driven JSON format. 

### Essential 
ules.mk
`make
VIA_ENABLE = yes
RGBLIGHT_ENABLE = yes
RGBLIGHT_ANIMATIONS = yes
LTO_ENABLE = yes
`

### Essential keyboard.json Snippet
`json
{
    "processor": "RP2040",
    "bootloader": "rp2040",
    "matrix_pins": {
        "rows": ["GP0", "GP1", "GP2", "GP3", "GP4", "GP5"],
        "cols": ["GP6", "GP7", "GP8", "GP9", "GP10", "GP11", "GP12", "GP13", "GP14", "GP15", "GP16", "GP17", "GP18"]
    },
    "diode_direction": "COL2ROW",
    "rgblight": {
        "pin": "GP25",
        "led_count": 18,
        "animations": {
            "all": true
        }
    },
    "ws2812": {
        "pin": "GP25",
        "driver": "vendor"
    }
}
`

## 3. VIA/Vial Compatibility

To ensure the board is detected by VIA/Remap:
1.  **Lighting Tag**: In your 
ia.json, ensure "lighting": "qmk_rgblight" is set.
2.  **Vendor/Product IDs**: Ensure they match in both keyboard.json and the VIA JSON.
3.  **Sideloading**: If using Remap, ensure the matrix definition matches the physical layout exactly to avoid "missing key" errors.

## 4. Hardware Routing Lessons
*   **GP25 for RGB**: Using GP25 for the WS2812B data line is a reliable standard.
*   **Differential Pairs**: Keep USB D+/D- traces as short as possible and matched in length.
*   **Decoupling**: Ensure each VCC pin on the RP2040 has a 0.1uF capacitor as close to the pin as possible.

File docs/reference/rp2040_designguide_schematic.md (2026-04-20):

# RP2040 Design Guide — canonical reference schematic

Source: [calliah333/RP2040-designguide](https://github.com/calliah333/RP2040-designguide) — `PCB/RP2040-Guide.pdf`. Mirrored at `../../NCKiser_refs/rp2040_designguide/RP2040-Guide.pdf`.

**What it is:** a **single-page KiCad 6.0.4 schematic** (dated 2021-12-07, "Sleepdealer" revision 0.1) that shows the complete canonical RP2040 implementation. Noah Kiser references this in the first video of his RP2040 keyboard series.

This schematic confirms every constant in `rp2040_keyboard_design.md` and adds a few:

## Reference designators from the PDF

| Ref | Part | Value |
|---|---|---|
| U3 | RP2040 QFN-56 | MCU |
| U1 | W25Q128JVSC | QSPI flash |
| U2 | USBLC6-2SC6 | USB ESD protection (alt to SRV05-4, same class) |
| U4 | XC6206PxxxMR | 3V3 LDO |
| J1 | HRO TYPE-C receptacle | USB_C_Receptacle_USB2.0 footprint |
| J2 | 1×4 header | SWD + 3V3 (SWCLK / SWDIO / GND / 3V3) |
| J3, J4, J5 | 1×11 headers | GPIO breakout expansion |
| Y1 | 12 MHz crystal | SMD 3225 |
| F1 | 500 mA PTC fuse | on VBUS |
| SW1 | SW_Push | USB_BOOT button, with R1 1k pulldown |

## Passive values (from the PDF)

| Ref | Value | Role |
|---|---|---|
| C1 | 100 nF | RP2040 3V3 decoupling |
| C2 | 1 µF | RP2040 internal 1V1 reg (VREG_VOUT) |
| C3, C17 | 22 pF | crystal load caps |
| C4 | 1 µF | (context-dependent decoupling) |
| C5 | 1 µF | LDO output |
| C6 | 100 nF | QSPI flash decoupling |
| C7 | 10 µF | main 3V3 bulk |
| C8 | 1 µF | |
| C9 | 100 nF | 3V3 decoupling |
| C10–C15 | 100 nF each | per-3V3-pin decoupling |
| C16 | 1 µF | LDO input |
| R1 | 1 kΩ | USB_BOOT button pulldown |
| R2 | 1 kΩ | (likely reset pull) |
| R3, R4 | **5.1 kΩ** | **CC1 / CC2 pulldowns** |
| R5, R6 | **27 Ω** | **USB D+/D− series** |
| R7 | 1 kΩ | **inline on XOUT** |

## Additions over the Gemini summary

1. **SWD header** (J2, 1×4) — call out in the schematic for debugger access. Pinout: SWCLK / SWDIO / GND / 3V3.
2. **USB_BOOT button** — SW_Push + R1 1kΩ pulldown on GPIO… (check silkscreen). Required to put the chip in bootsel mode without pulling DVDD. Include in any keyboard build even if hidden under the case.
3. **USB-C footprint name** — `USB_C_Receptacle_USB2.0` (standard KiCad symbol). USB 2.0-only, SBU1/SBU2 unused.
4. **ESD part** — `USBLC6-2SC6` is what calliah333 picked; interchangeable with SRV05-4. Both in SOT23-6.
5. **GPIO breakouts** — 3× 1×11 headers (J3, J4, J5) expose all user GPIO. Not needed in a keyboard, but useful for prototyping.

## Apply to DeltaSplit 75 rebuild

Use this PDF as the schematic sheet layout. In KiCad 10, open the PDF side-by-side with the schematic editor and replicate component placement + net names. Then attach the 86-switch matrix sheet (hierarchical) that scans columns → rows through RP2040 GPIO.

**BOM order (suggested source):** LCSC for all parts — they stock every P/N in the PDF.

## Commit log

2026-04-20 init: reorganize DeltaSplit 75 repo + add tracking docs + plate lint
    - flatten double-nested master dir
    - split files into case/{bezel,left,right}/{plate,middle,bottom}, pcb/gerbers, docs, archive
    - README + PLATES + BUILD + STATUS markdowns
    - scripts/lint_dxf.py: SCS-style DXF pre-flight (zero-len, dup-vtx, dangling endpoints, bbox overlap)
    - lint run: MX LEFT/RIGHT + ALPS+MX LEFT + ALPS RIGHT each have 1-6 orphan line endpoints from incomplete cutouts; documented in STATUS.md
    [ALPS LEFT B.dwg, ALPS LEFT B.dxf, ALPS RIGHT B.dwg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]
2026-04-20 docs: add dual-mode context (one-piece vs spread-split)
    DeltaSplit 75 has a detachable seam switch; board mounts in one unibody
    case OR two separate shells with a gap. Orphan line findings may be
    intentional break-away tabs, not defects — flagged for investigation.
2026-04-20 add KLE: deltasplit75_raw.json (86 keys)
    User-provided on-record layout. 75% with {x:2} gap per row = visual split.
    "Temp" keys are placeholder labels; seam-switch / spread-vs-onepiece
    variants not yet produced.
2026-04-20 docs: add RP2040 keyboard PCB design reference
    Noah-Kiser-derived extraction (via Gemini) covering:
    - RP2040 power + peripheral BOM (USB-C/LDO/QSPI/crystal/ESD)
    - 0.79375 mm CAD grid for 1U key math
    - Diode placement + SOD-123 bottom layer rules
    - Hotswap vs soldered multi-layout collision rules
    - Trace routing hierarchy (USB diff / crystal / power / matrix / GND pour)
    Drives the DeltaSplit 75 RP2040 rebuild track in STATUS.md.
2026-04-20 docs: inventory Noah Kiser reference repos
    Cloned 7 NCKiser repos to sibling NCKiser_refs/:
    - le_chiffre_keyboard_stm32: gold-standard full keyboard project template
    - TKL_VIDEO: raw KiCad 7 project with 15+ dated backups from tutorial
    - marbastlib: MX/Choc/USB-C/ProMicro footprint libraries (73 fps total)
    - Keebio-Parts.pretty: MCU + crystal + passive footprints
    - kiao: STM32F072 XIAO-class carrier reference
    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
2026-04-20 docs: add RP2040 reference schematic + KiCad toolchain + KLE placer workflow
    Sources from Noah Kiser's first RP2040 video:
    - ebastler/marbastlib (upstream, richer than NCKiser fork) cloned to NCKiser_refs/
    - zykrah/kicad-kle-placer (KiCad 7+ PCM plugin) cloned
    - calliah333 RP2040-Guide.pdf (single-page canonical KiCad 6 schematic) fetched
    New docs:
    - rp2040_designguide_schematic.md — ref-designator breakdown from the PDF
    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
2026-04-21 add scripts/case_to_3d.py: DXF -> STEP/STL extrusion macro
    FreeCAD macro that converts all 14 case DXF layers to solid STEP + STL:
    - Plates: 1.5 mm extrusion
    - Bezel / bottom / middle: 3 mm each
    - Middle layers (5 stacked in one DXF, 142 mm pitch): split by Y band,
    each extruded 3 mm and stacked in Z, then fused into a single 15 mm solid
    Wire assembly: greedy endpoint chaining from LINE/CIRCLE/ARC entities.
    Skips open chains (orphan segments, USB notch, stab cutouts — confirmed
    unfixable without DXF repair). Output to output/3d/*.step + *.stl.
2026-04-21 add output/3d STLs + fix case_to_stl.py polygon recovery
    Generated 14 STLs from all case DXF layers (standalone, no FreeCAD).
    Script fixes: (1) bbox fallback when outer boundary is broken (odd
    dangling endpoint) or too fragmented (largest poly < 40% bbox);
    (2) hole subtraction limited to polys < 15% bbox to avoid subtracting
    large valid sub-regions in complex ALPS+MX multi-layout plates;
    (3) Windows cp1252 encoding stripped from all print statements.
    Middle layers: 5-layer stacked DXF split by Y band (142 mm pitch),
    each extruded 3 mm, fused into single 15 mm solid.
2026-04-21 fix case_to_stl: extrude each polygon as-is, no boolean ops
    Previous approach subtracted inner polys from outer, producing merged
    flat sheets. Now each closed polygon from polygonize is extruded
    independently to the layer thickness and combined. Bezel rings, plate
    cutouts, and case features all retain their original DXF geometry.
    Middle layers: each of the 5 Y-band layers extruded at correct Z offset
    and combined into one STL (not fused into solid).
2026-04-21 fix case_to_stl: use interior-ring detection for plate material sections
    Plates whose outer boundary is closed in the DXF produce polygons with
    interior rings (switch/stab cutouts already encoded). Extrude those directly
    instead of doing bbox subtraction, which was inverting the geometry. Right
    plates with a broken outer boundary (1 dangling endpoint) fall back to
    bbox minus all cutout polygons.
2026-04-21 use mapbox-earcut for constrained triangulation of plates with holes
    Previous unconstrained Delaunay + centroid filter produced triangles
    spanning across switch cutouts, leaving open or malformed holes. earcut
    respects interior rings as real holes and yields a valid closed mesh.
2026-04-22 Phase A Complete: Reconstructed KiCad schematic, fixed plate DXFs, and generated KLE JSONs
    - Fixed orphan switch lines in MX LEFT/RIGHT standard plates.
    - Created missing MX RIGHT B COSTARS plate.
    - Generated 86-key onepiece and 84-key spread KLE JSONs.
    - Built KiCad 9.0 schematic with 86-key matrix using net labels.
    - Linked Keebio-Parts library in pcb/fp-lib-table.
    - Updated documentation for 3D printing and USB-C interconnect.
    [DeltaSplit_ProMicro.kicad_sch, MX LEFT B.dxf, MX RIGHT B COSTARS.dxf]
2026-04-24 feat: complete original replication with switch/diode placement and nets
    [DeltaSplit_ProMicro.kicad_sch]
